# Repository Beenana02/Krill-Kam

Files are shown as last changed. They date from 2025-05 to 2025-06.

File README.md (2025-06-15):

# Krill Kam 

Check out the Krill Kamera! A raspi 4 custom camera that's fully handheld.   
*PSA it's fish themed (that's why it's a krillfish camera name)*

### What is the Krill-Kam

The krill kam uses a Raspi pi cam module and Raspi to basically create a custom digital camera. It's based of the old sony handycam. It comes with it's own screen and app to take and view photos or videos. It can also record audio from a mini USB mic. Lastly, it is all powered with a simple LiPo battery!

### Why camcorder?
I wanted the camera to be more handycam shaped because my personal handycam's microphone and speaker are broken. I wanted to originally fix this, but I decided I would challenge myself with creating my own camera! (Plus repairing the Handycam seemed pretty sketchy :cry:)

camcorder plus krill fish = krill kam  

## Photos

### Camera itself

Uses USB storage to save photo and video
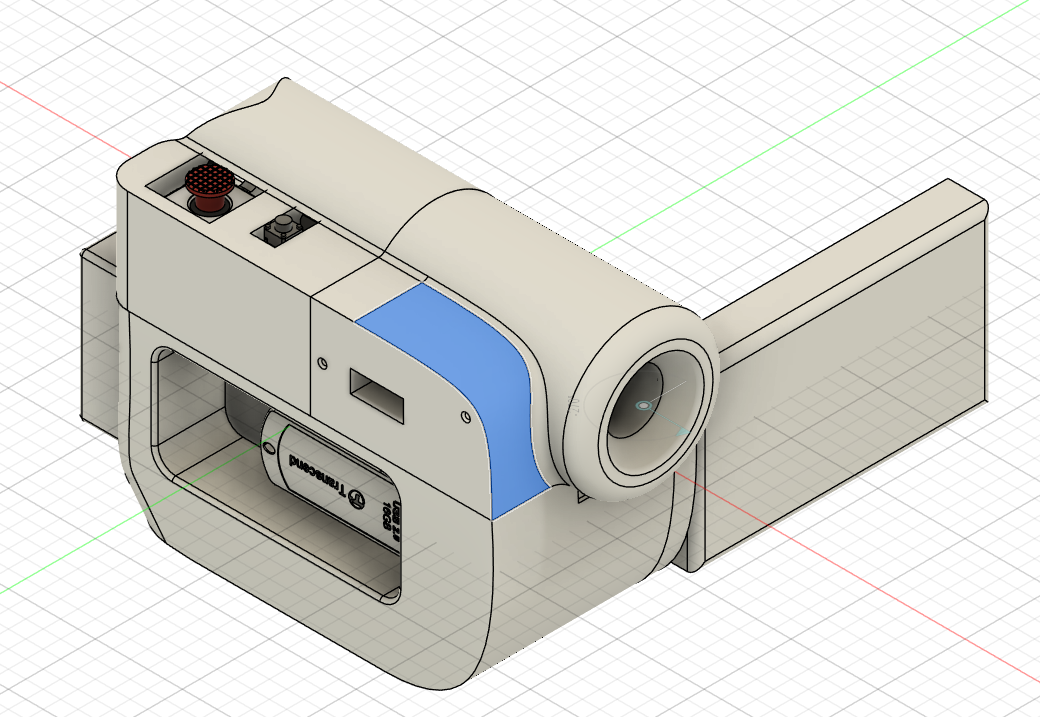
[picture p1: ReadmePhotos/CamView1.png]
view1
  

Has an inner panel for extra buttons and screens!
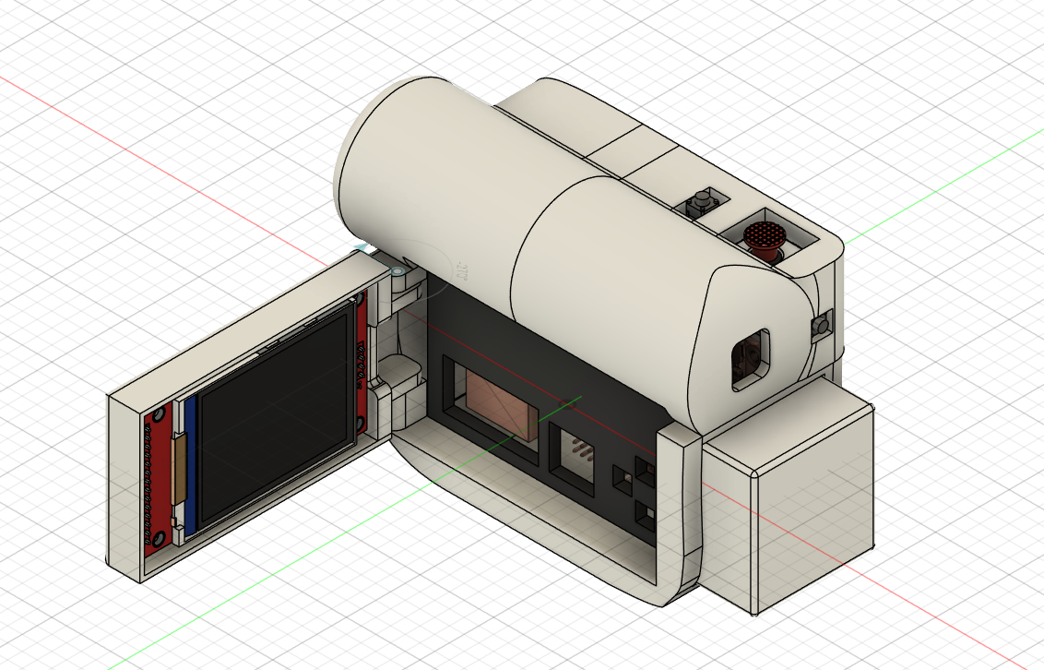
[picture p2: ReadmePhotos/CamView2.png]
view2
  

Arm with screen can open and close
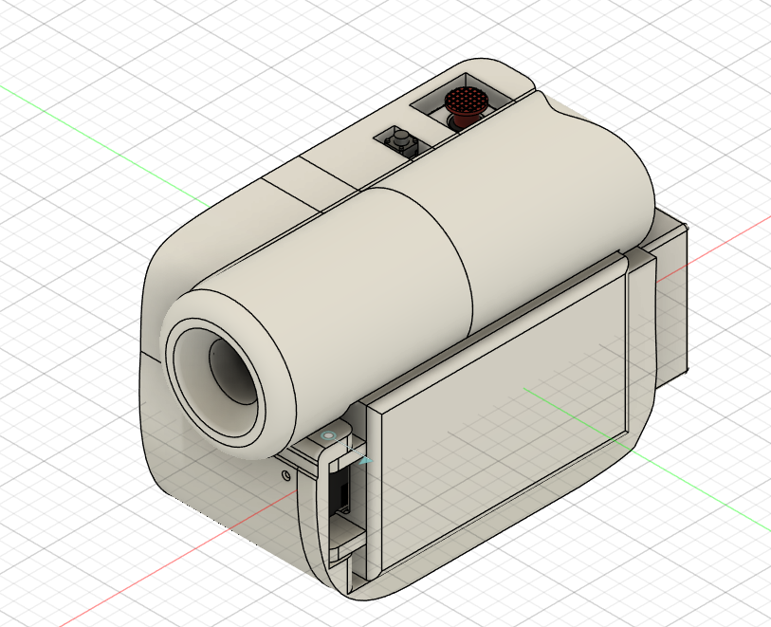
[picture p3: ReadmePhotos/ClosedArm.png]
Arm


> For more specific info read the journal!

## Wiring Diagram

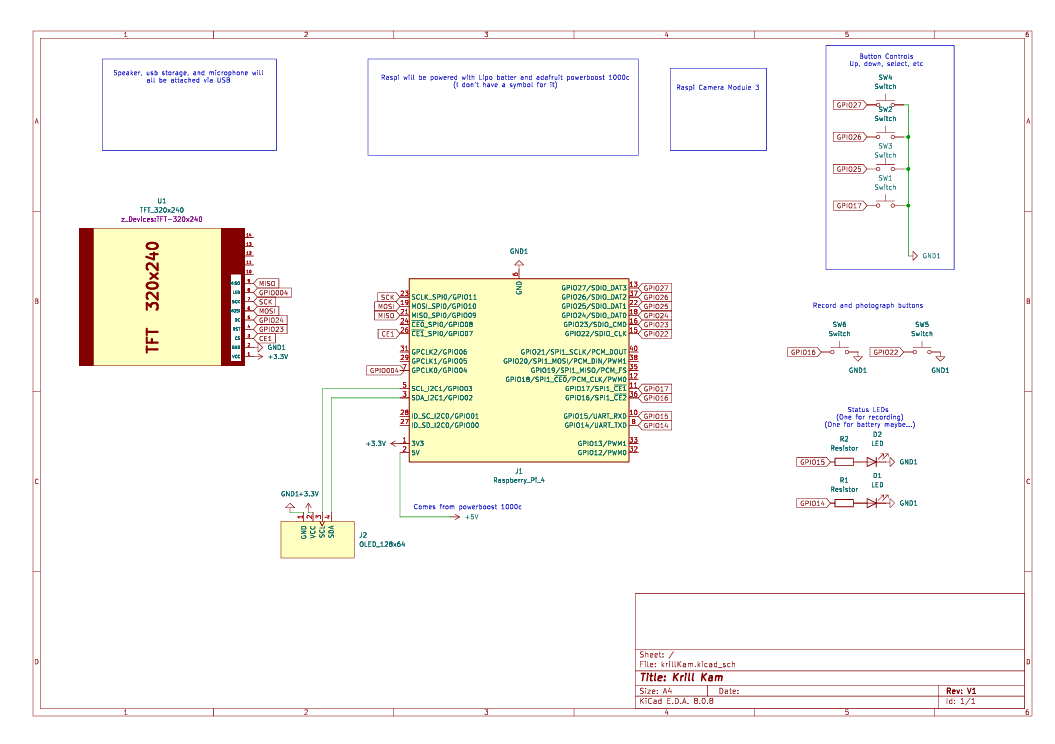
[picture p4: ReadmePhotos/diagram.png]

>look at the pdf for better view of diagram  

## BOM  

If it says own, that means I already have the item. Hopefully format is fine, I used a sheets to markdown generator so it may look a little off. Also total cost is **$126.07** this includes shipping, taxes, etc!

| Item Number | Description | Quantity | Link | Price  |
| --- | --- | --- | --- | --- |
| 1 | 2.4" TFT SPI Screen w/ Touchscreen | 1 | [Link](https://www.aliexpress.us/item/3256806129218488.html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) | 7.95 |
| 2 | PowerBoost 1000c | 1 | [Link](https://www.adafruit.com/product/2465) | 19.95  |
| 3 | Raspi 4 B | 1 | own | 0 |
| 4 | Raspi Cam module 3 | 1 | own | 0 |
| 5 | Mini 2-Axis Analog Thumbstick | 1 | [link](https://www.adafruit.com/product/2765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) | 2.5 |
| 6 | Analog Mini Thumbstick Breakout Board | 1 | [link](https://www.adafruit.com/product/3246) | 1.5 |
| 7 | Variety Pack Heatpress Inserts | 1 | [link](https://www.aliexpress.us/item/3256805603102147.html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) | 6.88 |
| 8 | USB 3.0 Right Angle Adapter | 1 | [link](https://www.aliexpress.us/item/3256805983682595.html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) | 1.49 |
| 9 | Hook Up wire 22awg | 1 | [link](https://www.digikey.com/en/products/detail/adafruit-industries-llc/1311/6198255) | 15.95  |
| 10 | LiPo 6000mAh battery 3.7v | 1 | [link](https://www.amazon.com/MakerHawk-6000mAh-Rechargeable-Protection-Insulated/dp/B0D7MBBS5N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) | 16.99  |
| 11 | eye screws for charms | 1 | [link](https://www.aliexpress.us/item/2255800041458653.html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) | 2.06 |
| 12 | Mini USB microphone | 1 | [link](https://www.adafruit.com/product/3367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) | 5.95 |
| 13 | Mini OLED screen (display battery health) | 1 | own | |
| 14 | Heatsink for Raspi | 1 | [link](https://www.adafruit.com/product/3084) | 0.95 |
| 15 | USB speaker | 1 | [link](https://www.adafruit.com/product/3369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) | 12.5 |
| 16 | Perfboard | 1 | [link](https://www.aliexpress.us/item/3256807162768193.html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) | 7.27 |
| 17 | Micro USB male to female cable | 1 | [link](https://www.amazon.com/Extension-Micro-B-Transferring-Suitable-Samsung/dp/B07MC7YSR2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) | 5.99 |
| 18 | Camera hand strap | 1 | [link](https://www.aliexpress.us/item/3256803849243891.html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) | 2.75 |
| 19 | Buttons | 6 | own | |
| | Cost without taxes/ shipping | | | 110.68 |
| | Cost final | | added $5 extra incase I got some of the taxes wrong | 126.07 |

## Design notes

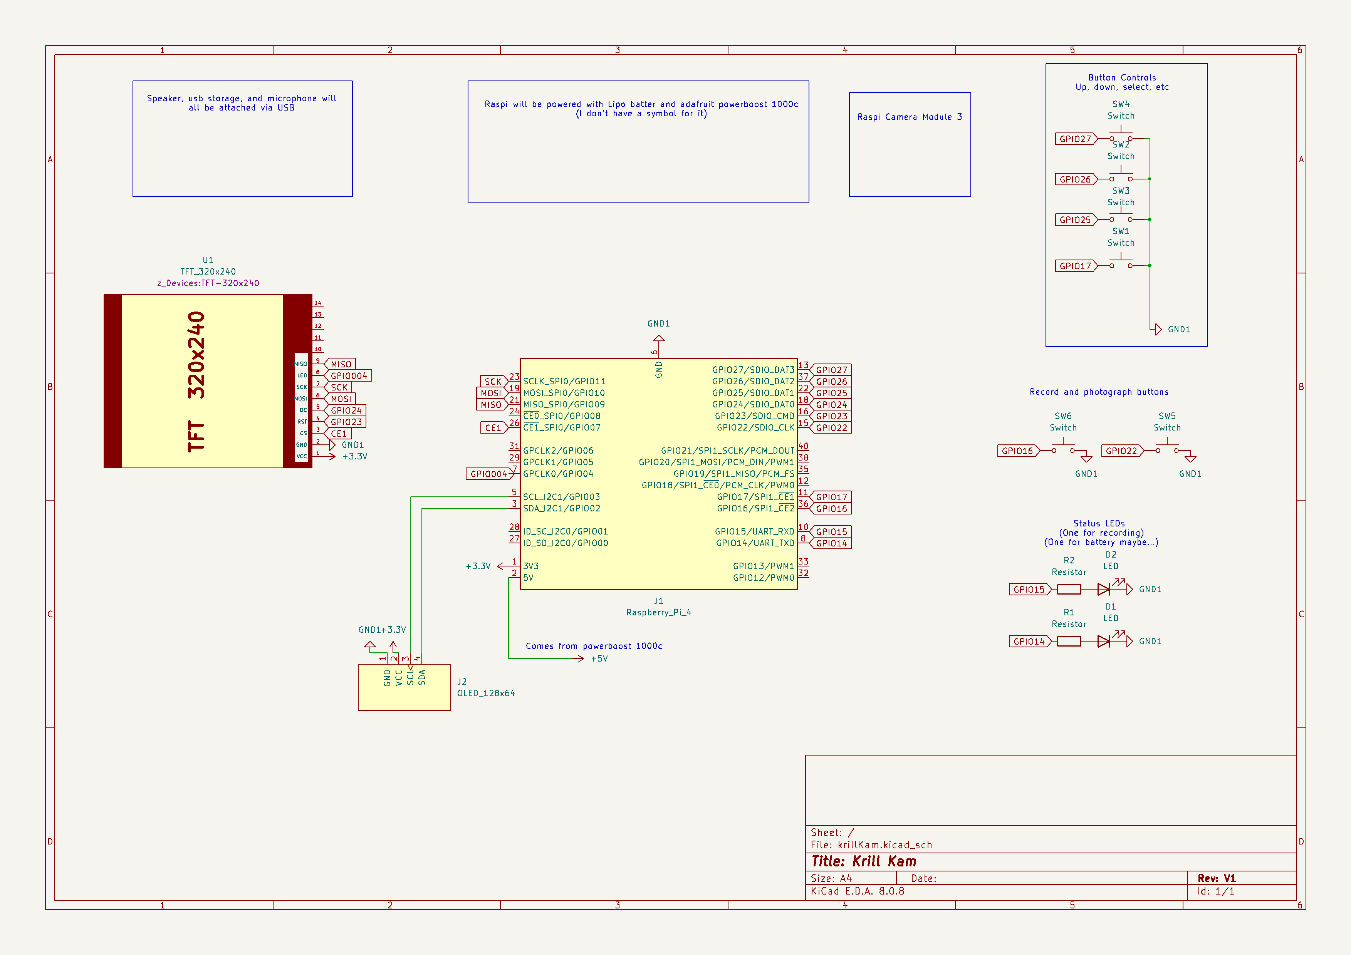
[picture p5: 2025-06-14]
image.png

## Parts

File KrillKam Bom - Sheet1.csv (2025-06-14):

Item Number | Description | Quantity | Link | Price
1 | 2.4" TFT SPI Screen w/ Touchscreen | 1 | Link | 7.95
2 | PowerBoost 1000c | 1 | Link | 19.95
3 | Raspi 4 B | 1 | own | 0
4 | Raspi Cam module 3 | 1 | own | 0
5 | Mini 2-Axis Analog Thumbstick | 1 | link | 2.5
6 | Analog Mini Thumbstick Breakout Board | 1 | link | 1.5
7 | Variety Pack Heatpress Inserts | 1 | link | 6.88
8 | USB 3.0 Right Angle Adapter | 1 | link | 1.49
9 | Hook Up wire 22awg | 1 | link | 15.95
10 | LiPo 6000mAh battery 3.7v | 1 | link | 16.99
11 | eye screws for charms | 1 | link | 2.06
12 | Mini USB microphone | 1 | link | 5.95
13 | Mini OLED screen (display battery health) | 1 | own
14 | Heatsink for Raspi | 1 | link | 0.95
15 | USB speaker | 1 | link | 12.5
16 | Perfboard | 1 | link | 7.27
17 | Micro USB male to female cable | 1 | link | 5.99
18 | Camera hand strap | 1 | link | 2.75
19 | Buttons | 6 | own
 | Cost without taxes/ shipping |  |  | 110.68
 | Cost final |  | added $5 extra incase I got some of the taxes wrong | 126.07

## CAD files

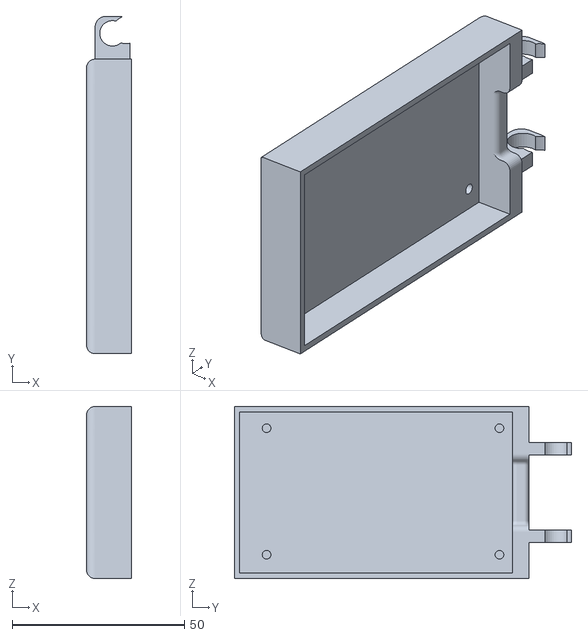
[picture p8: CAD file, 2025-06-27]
Case/V3/V3_Arm.stl
13.1 x 97.9 x 49.9

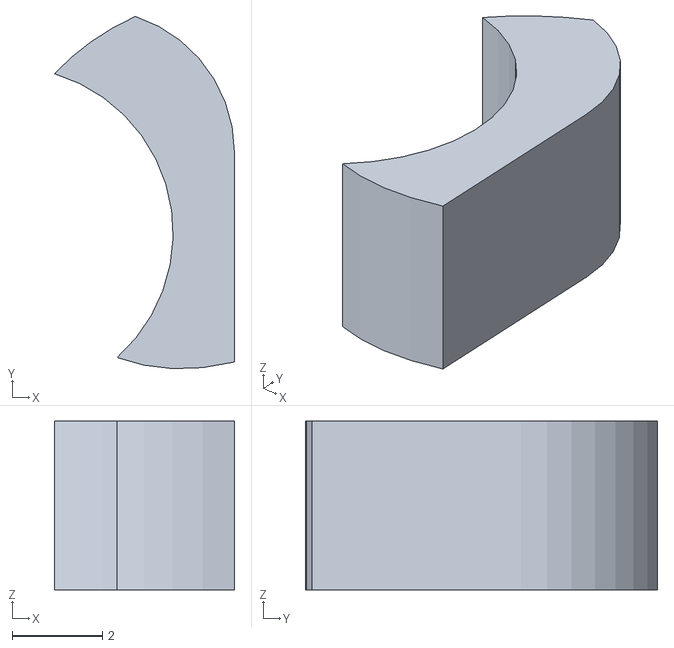
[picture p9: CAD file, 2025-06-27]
Case/V3/V3_ArmLock.stl
3.99 x 7.80 x 3.73

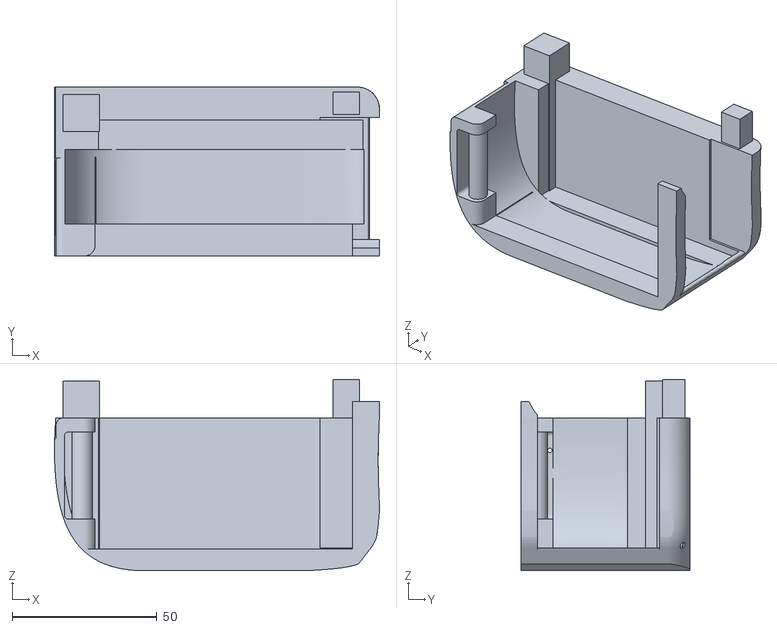
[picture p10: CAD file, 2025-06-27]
Case/V3/V3_Base.stl
112.4 x 58.4 x 66.2

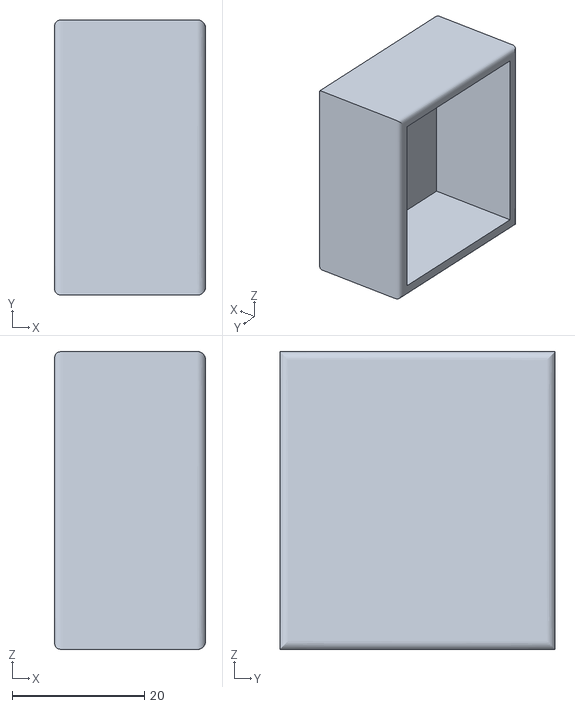
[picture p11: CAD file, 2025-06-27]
Case/V3/V3_FakeBatteryBack.stl
22.9 x 41.6 x 45.0

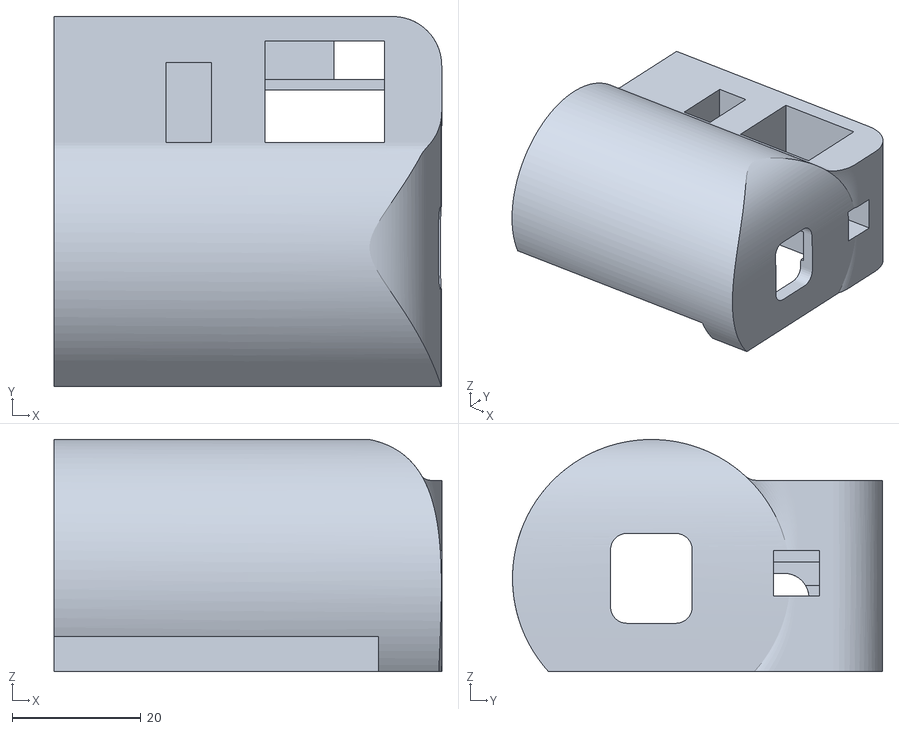
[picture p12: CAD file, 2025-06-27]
Case/V3/V3_Top1.stl
60.2 x 57.5 x 36.1

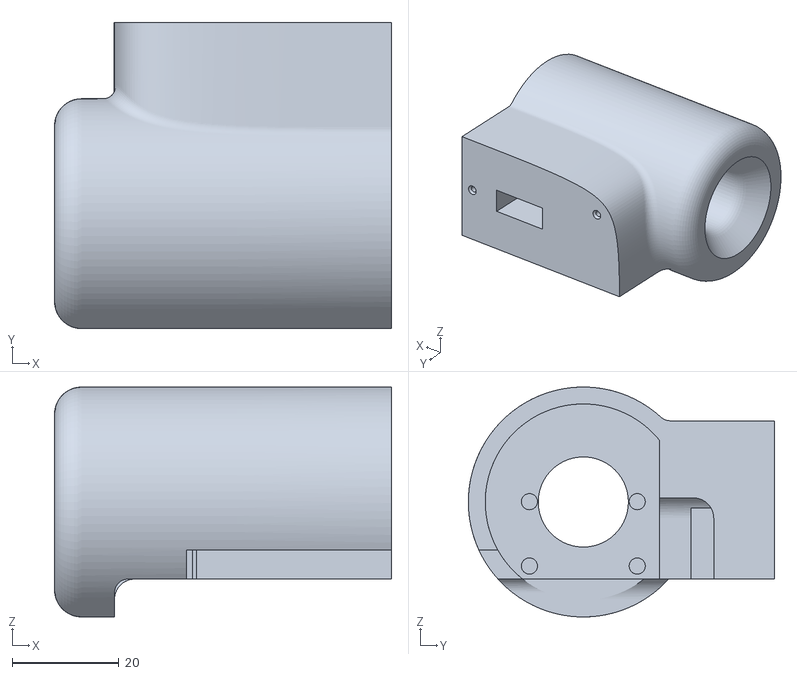
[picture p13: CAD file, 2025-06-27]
Case/V3/V3_Top2.stl
63.3 x 57.5 x 43.2

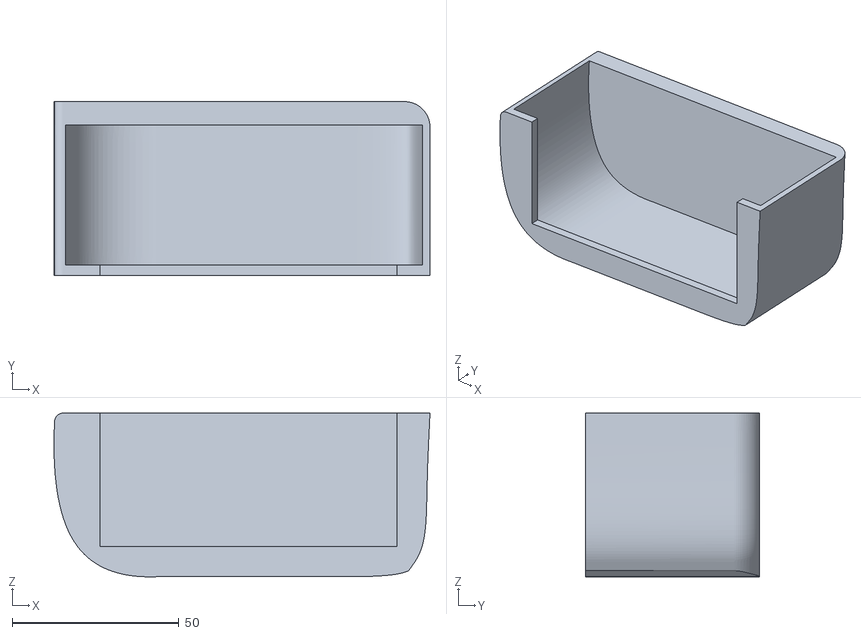
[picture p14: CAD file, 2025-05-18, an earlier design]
Case/V1/Base1.stl
112.7 x 52.1 x 49.1

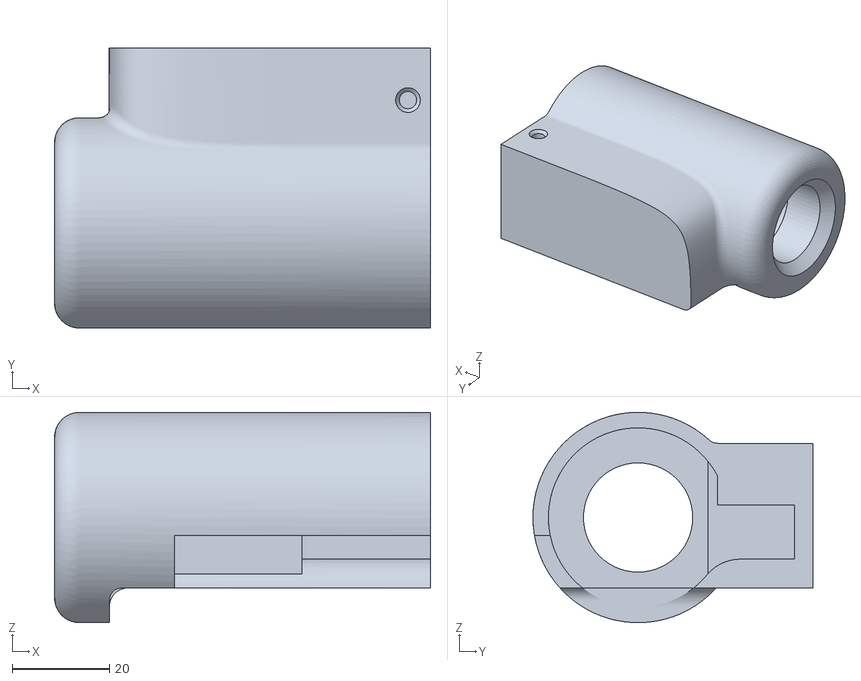
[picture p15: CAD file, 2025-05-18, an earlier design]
Case/V1/Top2.stl
77.2 x 57.5 x 43.2

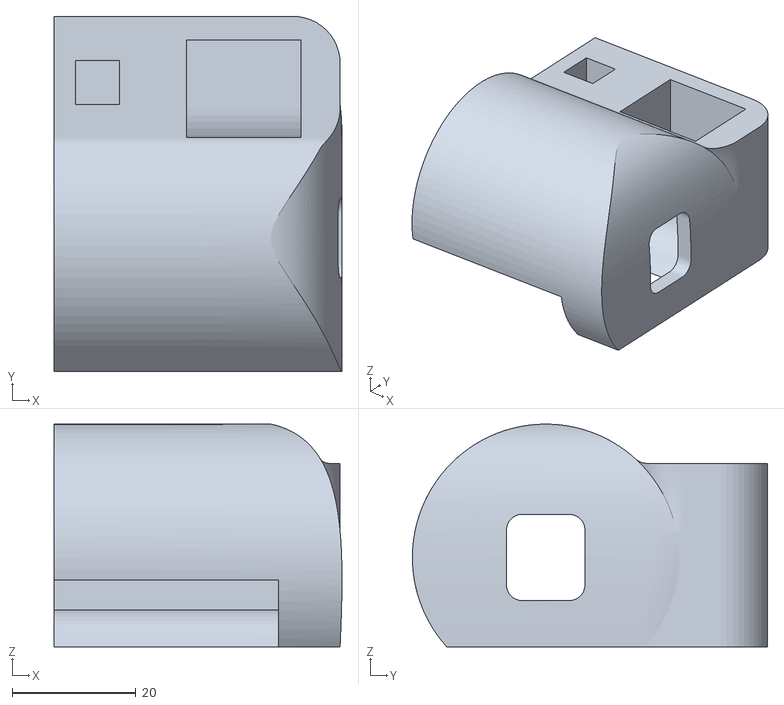
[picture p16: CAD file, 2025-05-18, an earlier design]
Case/V1/Top1.stl
46.6 x 57.5 x 36.1

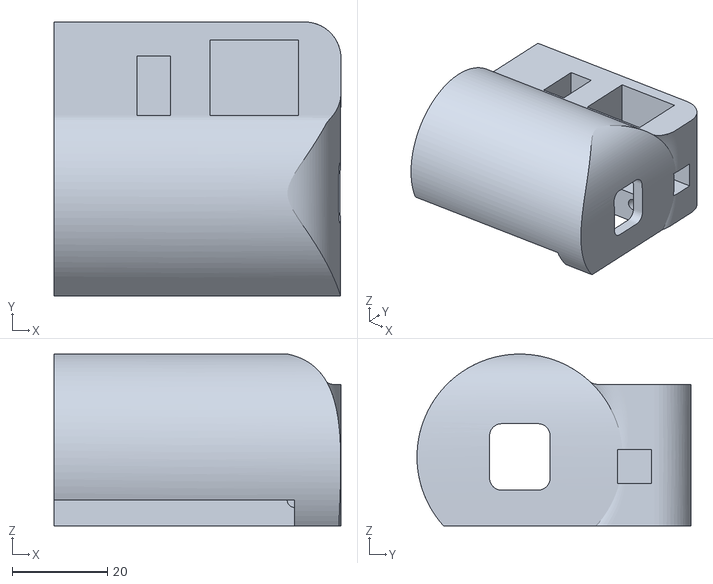
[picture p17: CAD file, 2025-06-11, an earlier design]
Case/V2/TopSplit2.stl
60.2 x 57.5 x 36.1

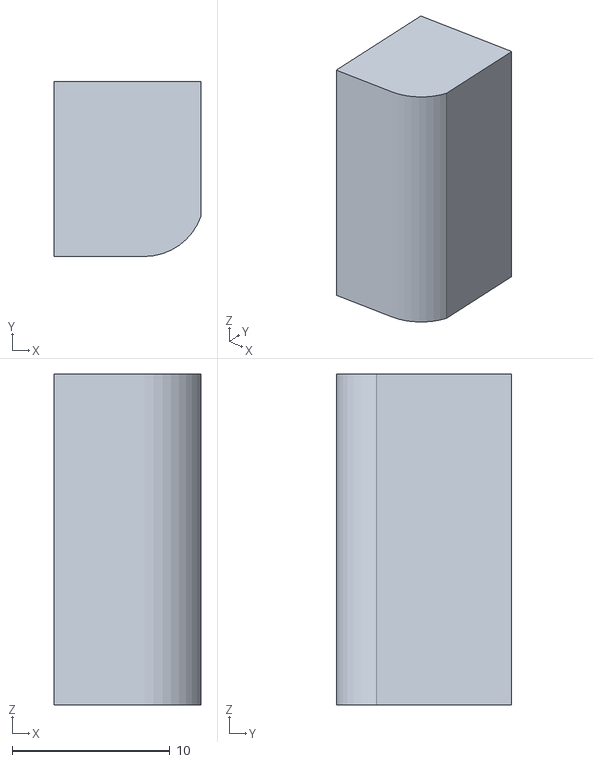
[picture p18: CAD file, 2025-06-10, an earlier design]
Case/V2/HingeHider.stl
9.32 x 11.1 x 21.0

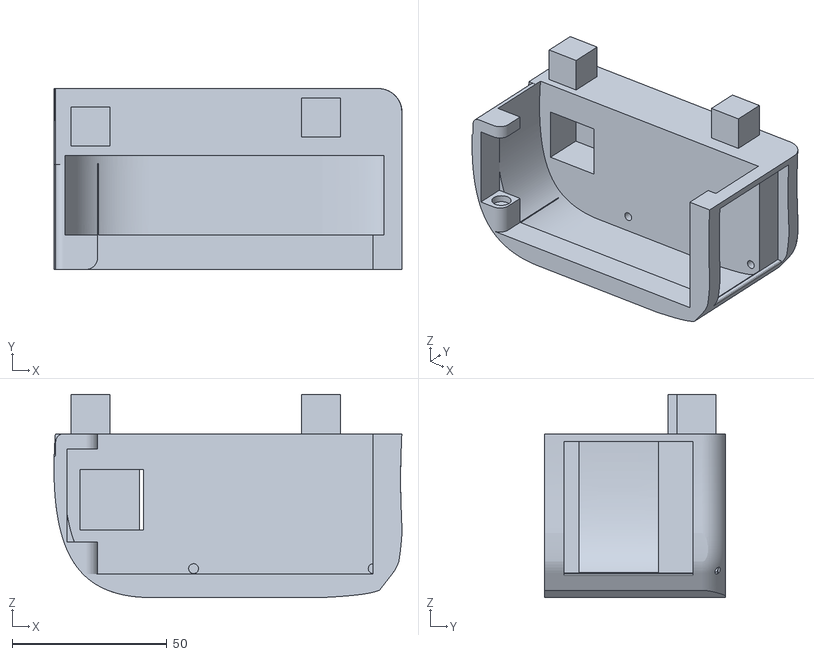
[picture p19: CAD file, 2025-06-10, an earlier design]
Case/V2/V2Base.stl
112.4 x 58.4 x 65.6

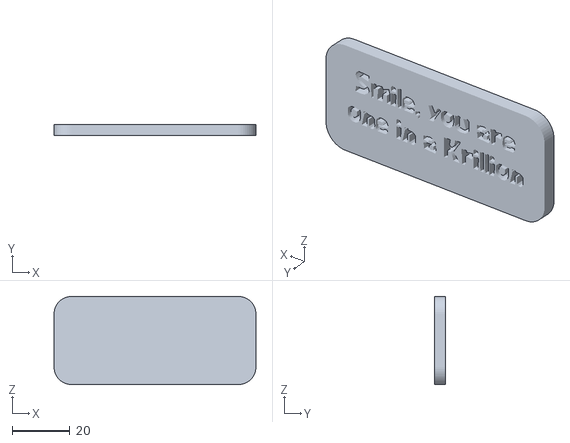
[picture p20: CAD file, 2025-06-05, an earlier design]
Case/V2/StoragePanel.stl
69.8 x 3.81 x 30.5

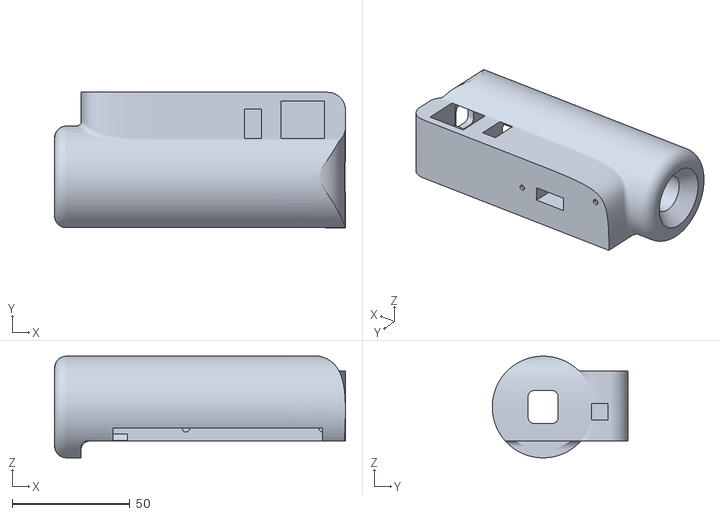
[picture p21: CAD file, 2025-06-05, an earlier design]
Case/V2/V2Top.stl
123.5 x 57.5 x 43.2

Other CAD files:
Case/V2/ScreenArm.stl
Case/V2/TopSplit1.stl
Case/V2/BatteryHolder.stl
Case/V2/InnerPanel.stl

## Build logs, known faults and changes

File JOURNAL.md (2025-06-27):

---
title: "Krill Kam"
author: "Gabi"
description: "Raspi-4 camera inspired by the Handycam"
created_at: "2025-05-16"
---

# Krill Kam Updates

Howdy wanna see the krill kam grow? 

Check out the updates below! :eyes::shrimp: [^1]
[^1]: I've spent 27.5 hours total on this project so far 😺

## May 16th: Sketching
Got in a rough idea of what I want the Camcorder to look like. It is based off the Sony Handy Cam that I have at home. 

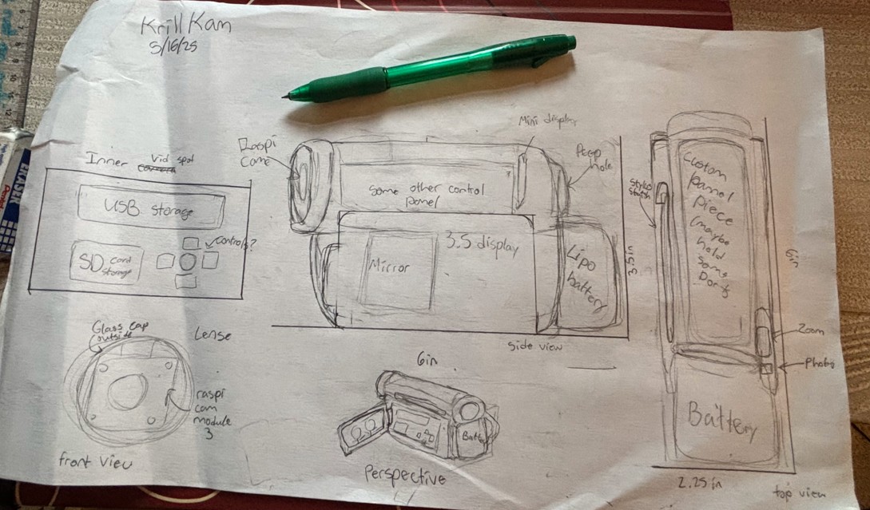
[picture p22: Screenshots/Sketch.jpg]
Planning Sketch


> Time Spent (Sketching) ~ 1 hour

## May 17th: First CAD & Print
Today I was just creating the Basic CAD model for the camera. I plan on making a full CAD when I figure out what parts I'll use. I already have a screen and raspi 4 at home so I have some basic dimensions for that.  

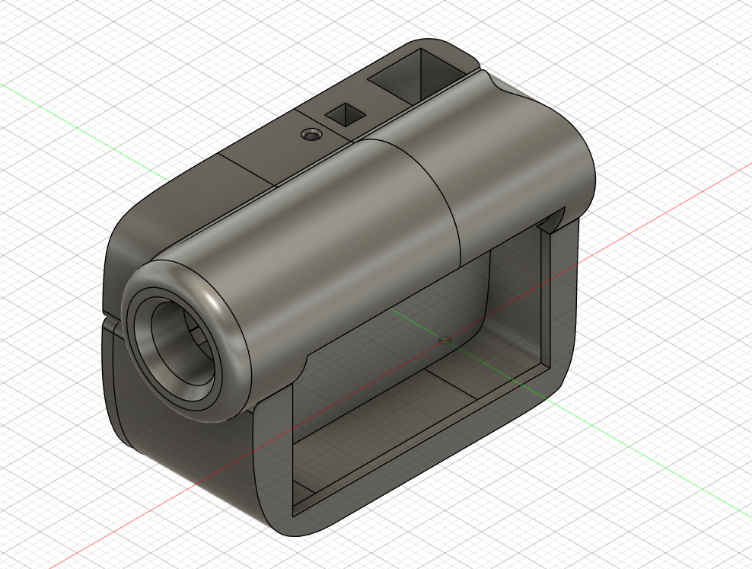
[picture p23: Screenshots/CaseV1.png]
First CAD


> Time Spent (CAD and printing) ~ 2.5 hours

## May 18th: Updating CAD

Didn't do too much today, just focused on updating the CAD model based on how the first CAD printed. Found some issues with clearance and fitting the Raspi in the actual shell. I revamp the inside to have a notch for the raspi and enough room for wires, buttons, proto boards, etc. Anyways, I still need to work on the actual pull out screen part and battery compartment.  

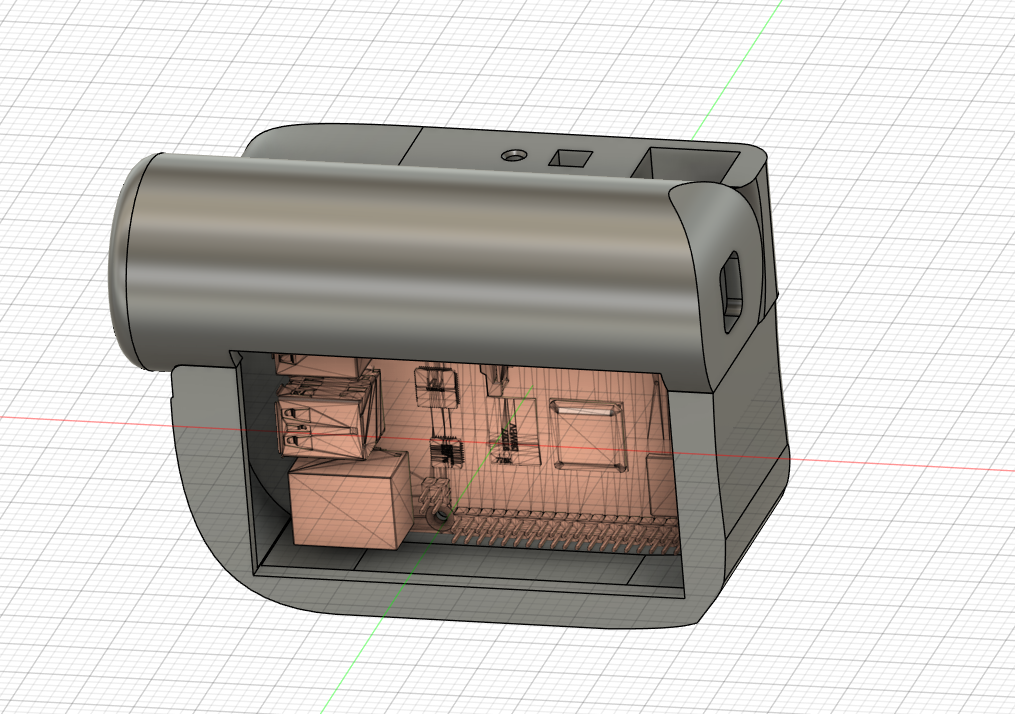
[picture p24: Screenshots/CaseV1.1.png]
Updated Case


> Time Spent (CAD) ~ 1 hour

## May 25th: Arm In CAD

Today I wanted to get the arm part with the hinge modeled in Fusion. This was my first time modeling a hinge and using the join feature in fusion. I went off a hinge design based on Maker's Muse's snap hinge in his video "Incredibly Handy 3D Printed Hinges!". I got the hinge to work with a bit of struggle at first, but overall I'm happy with the model. I plan on printing out the model one more time to figure out sizing, but the only thing left is to find where I'll put the power supply in the case.  

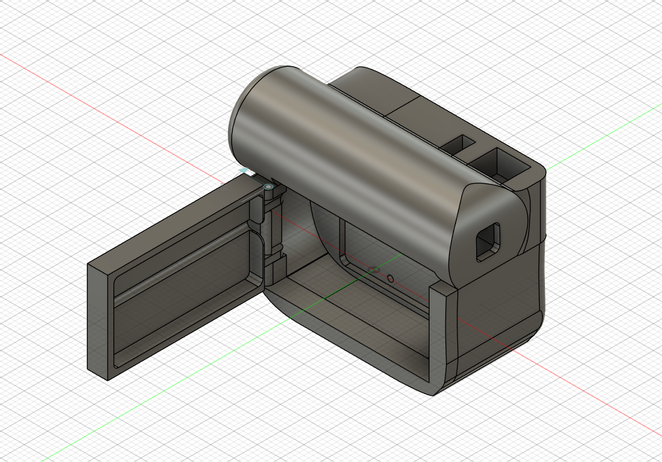
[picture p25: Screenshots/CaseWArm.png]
Cam with a arm to hold screen


> Time Spent (CAD) ~ 3 hours

## May 30th: Battery holder in CAD + some shopping

I modeled a little case on the end of my camera to hold the batteries and some remodeling on the holes for buttons. I'm still not sure what battery type i'll be using but I'm leaning towards a Li-Po with 5v converter and battery charger PCB like the Adafruit PowerBoost 1000. For the shopping, I think I've decided on using the Waveshare 2in touch display module for my main screen and the 0.85 LCD display module for the view hole screen. I plan on writing some test scripts just to get the camera working, but I won't be able to test the displays until I get them.  
 
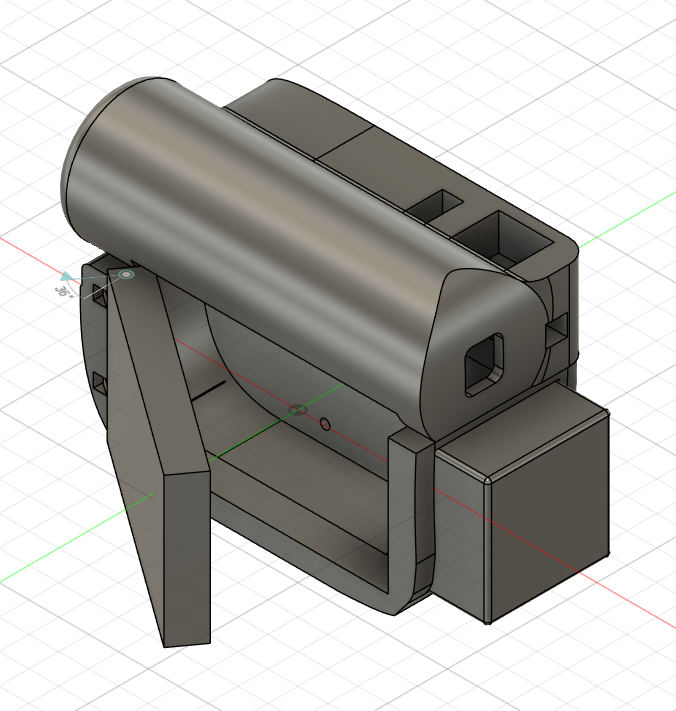
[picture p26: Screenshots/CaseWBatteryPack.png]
Cam with battery pack


> Time Spent (CAD) ~ 1.5 hours

## June 4th: Battery holder in CAD + some shopping

Today I coded some more on the camera app script by adding in new features to allow button presses to turn on and off the preview. I also worked a bit on the CAD and finally decided on the screen I will use for the camera. I'm going with a 2.4" TFT display since it fits perfectly inside my arm.  
 
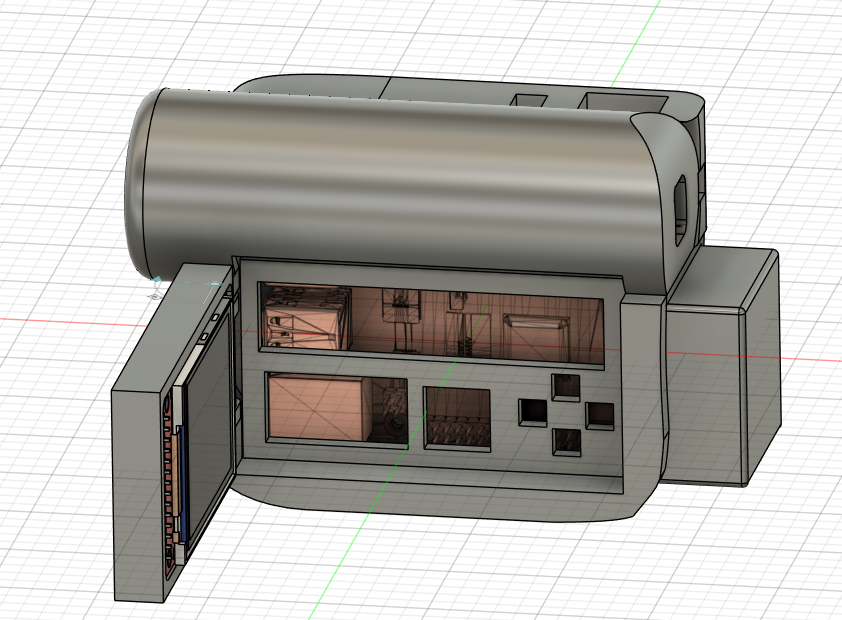
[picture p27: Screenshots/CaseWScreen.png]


> Time Spent (CAD+Code) ~ 1 hour

## June 5th: V2 of model DONE!

The case is done! I modeled in a spot to place the USB flashdrive in. I plan on using a flash drive to store the photos. I also place in components such as the buttons on the top of the case (not in picture). Lastly, I added in some text and remodeled the arm/ screen holder to have points to drill in the screen. The STL files are available in the [case folder](Case/V2).  

Also make sure to check out the [video](Screenshots/KrillKamCaseV2.mp4) in the screenshots folder for a short overview of the camera model.  

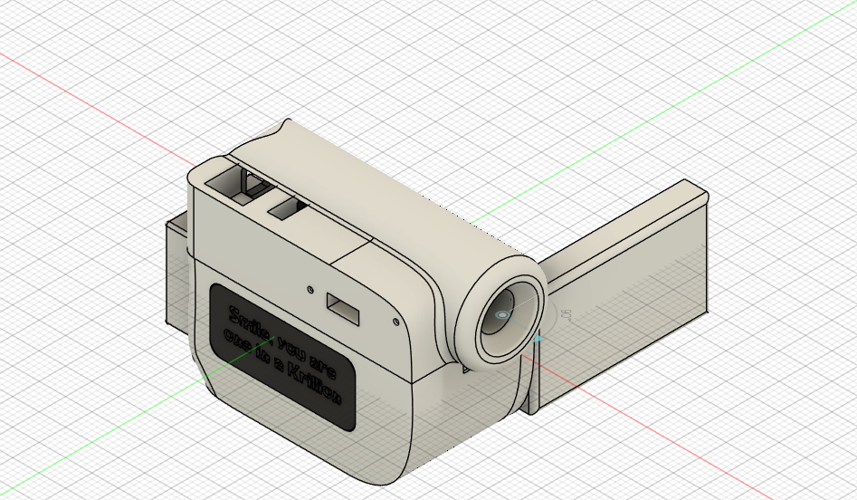
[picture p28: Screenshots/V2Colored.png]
Krill Kam Colored


> Time Spent (CAD) ~ 2.5 hours

## June 8th: Finished BOM

Today I began printing out the parts for krill kam case. I also finished the BOM of what items I need to buy. The total came to around $110 without shipping, but I'm sure with coupons and deals I will be able to get that price down. Also I settled on getting the battery off of Amazon even though it was pricey just because of shipping reasons. Anyways below is a photo of the pieces I have printed out so fall (arm, battery shell, and USB panel cover) more is printing now!   

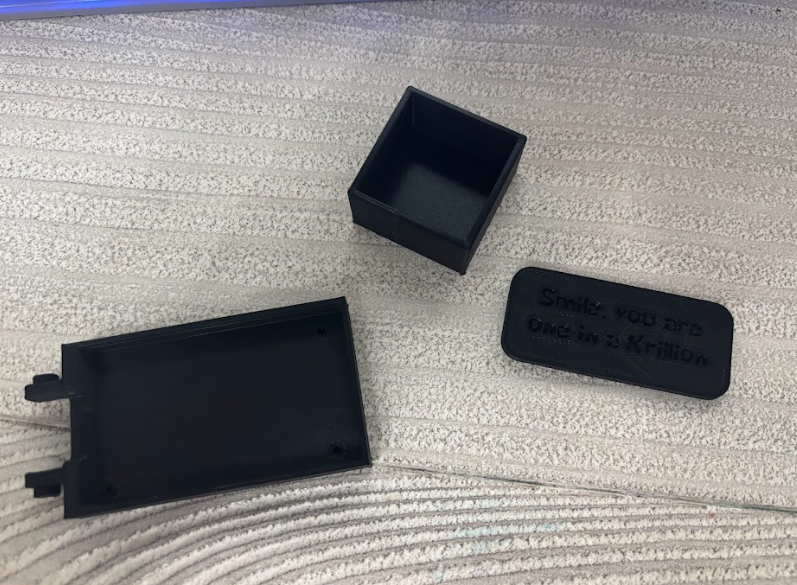
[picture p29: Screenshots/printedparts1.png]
arm, battery shell, and USB panel cover


> Time Spent (CAD) ~ 0.5 hours

## June 9th: Updated Hinge design

Today I printed out the base and notice 3 problems with clearances.  

1. I couldn't get the battery shell to fit in smoothly, so I added in some extra clearance to the hole on the back of the base.
2. The USB panel cover didn't fit in, so I added more clearances.
3. Lastly, the arm couldn't be attached to the base, so I got rid of the notch in the center and will print that part on its own and glue it back in.    

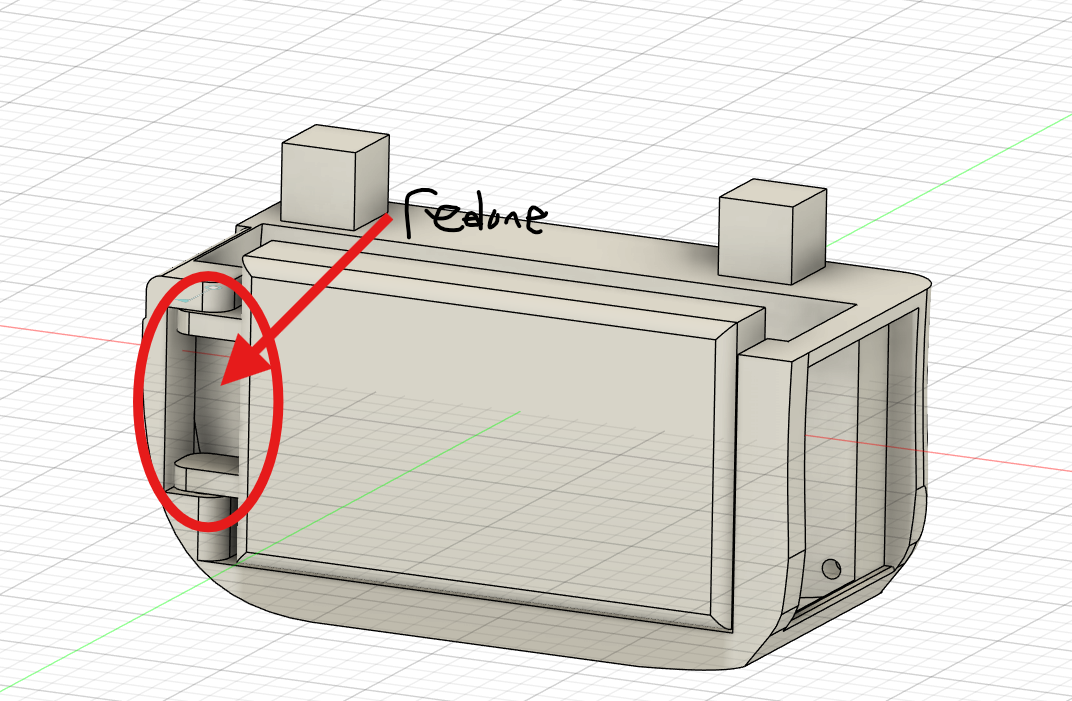
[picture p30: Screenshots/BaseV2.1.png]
fixed hinge


> Time Spent (CAD) ~ 0.5 hours

## June 11th: Printed case!

I fixed the problems with the base and reprinted the parts. I now have a full shell of the krill kam! I also did a bit of work on the gui code, but still working on layout stuff.  

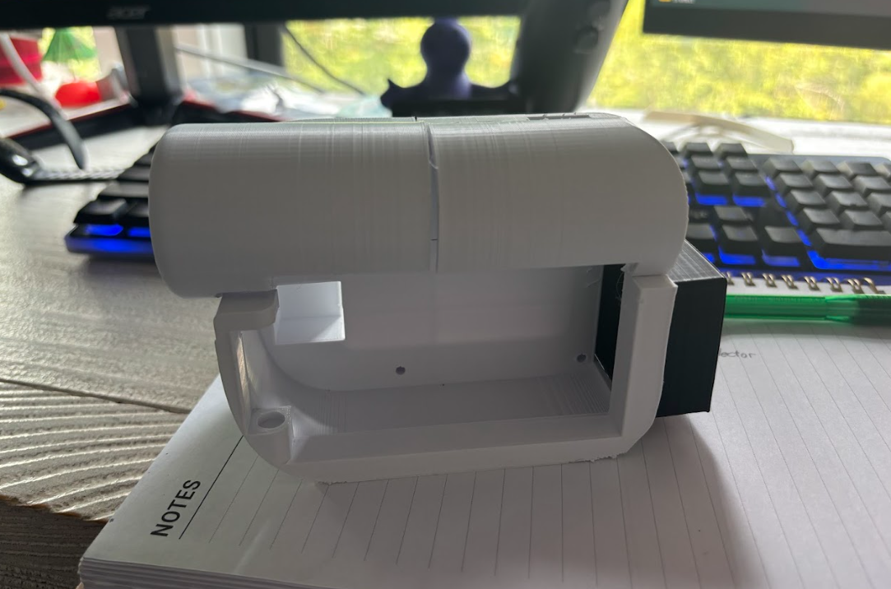
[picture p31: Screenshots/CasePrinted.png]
Case


> Time Spent ~ 1 hour

## June 12th: GUI with live camera feed

Today I got a background on my camera app, along with a live feed of the camera using OpenCV. I watched some of clear code's "The ultimate introduction to modern GUIs in Python [ with tkinter ]" to get the background image working and general knowledge on Tkinter. I also used Jake's Science Shop's "Adding a Webcam Stream to our Python - Tkinter Drone Controller | Part 2: GUI Video Stream" video to get OpenCV working with my app. Now I just need to fix the scaling issues with the camera and add in the rest of app features. I want a photo viewing mode, camera controls like zoom and focus, accurate time/date, and fun fish themed features! For now I've been using frutiger aero photos as my background, but I plan to shift into creating my own icons and backgrounds using pixel art!   

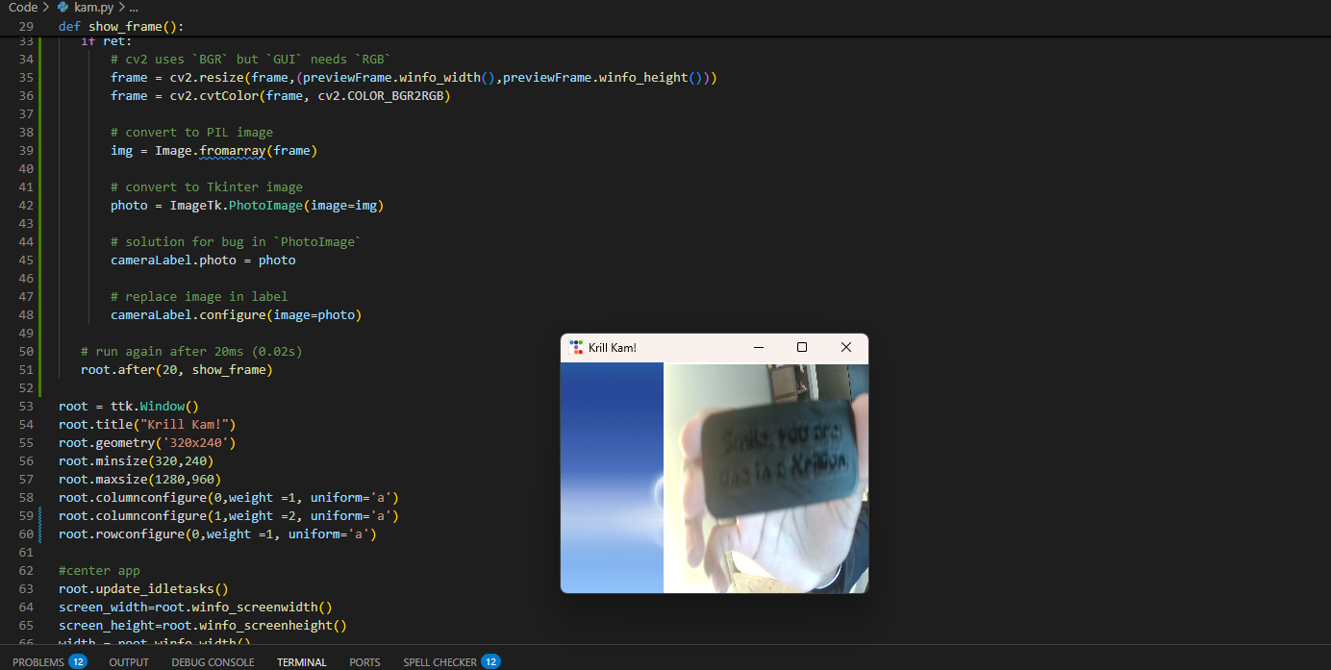
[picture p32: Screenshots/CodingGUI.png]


> Time Spent ~ 3 hours

## June 13th: Fixed camera feed and read me

I spent all of today trying to fix the camera feed so that the camera aspect ratio stays the same no matter the screen size. I got it to work using some ratio of camera height to width and comparing it with the window height and width. The code I learned yesterday when creating a background that resizes with app was what I based off today's code. I also added place holder buttons as well. Lastly I got my readme polished and I think I'm ready to submit for my grant. Hopefully I can get the screen part soon(it will help me a lot with creating the GUI).  

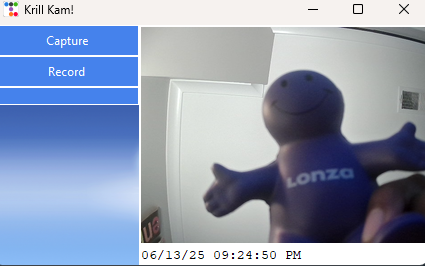
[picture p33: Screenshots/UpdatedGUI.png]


> Time Spent ~ 3 hours

## June 15th: new windows on GUI

Today I used the top level widget to create 2 new windows for the app. I now have a window for powering off the camera and a window to review photos. The window can't quite cycle through photos yet, but I am working on that at the moment. I think i'll try the same idea as I saw in geeks for geeks tutorial on creating a image viewer app with tkinter.    

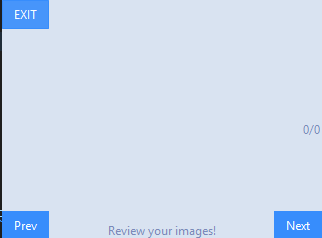
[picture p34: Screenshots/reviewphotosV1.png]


> Time Spent ~ 2 hours

## June 16th: Photo review works

I got the photos to cycle through using PIL to load the images and a custom function to make the photos fit to screen. Lastly, I got the photo buttons to work and allow the user to go forwards and backwards through the photos. I also used the OS library to make sure that only photo images would load in the photo review window. 

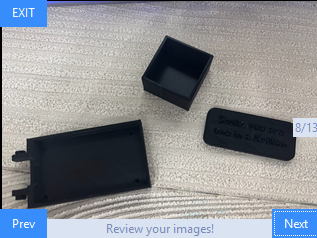
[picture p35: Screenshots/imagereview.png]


> Time Spent ~ 1 hour

## June 18th: Power Down window done

I finished up the power down menu today. I made a simple background using a photo I found from NASA. I then added some text in canva and saved the photo as a png. Lastly, I updated the code to display the image and I think it looks pretty good   

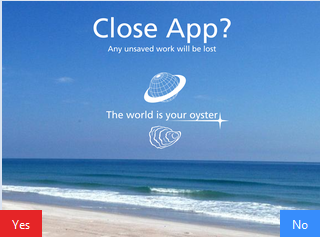
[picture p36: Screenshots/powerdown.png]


> Time Spent ~ .5 hours

## June 23th: Re-CAD

I was gone a bit for a vacation, but today I got the battery for the camera in the mail. It was way bigger than I had modeled for and I might have accidentally read the measurements on the product wrong. So today was re-working the cad to allow the battery to fit in the camera base. To get the battery to fit, I had to remove the usb storage compartment to make space for the battery. As of now I'm not sure what to remodel in order to get the usb flashdrive to fit. My plan is to just have it where the inner panel will be or in the old battery holder section 

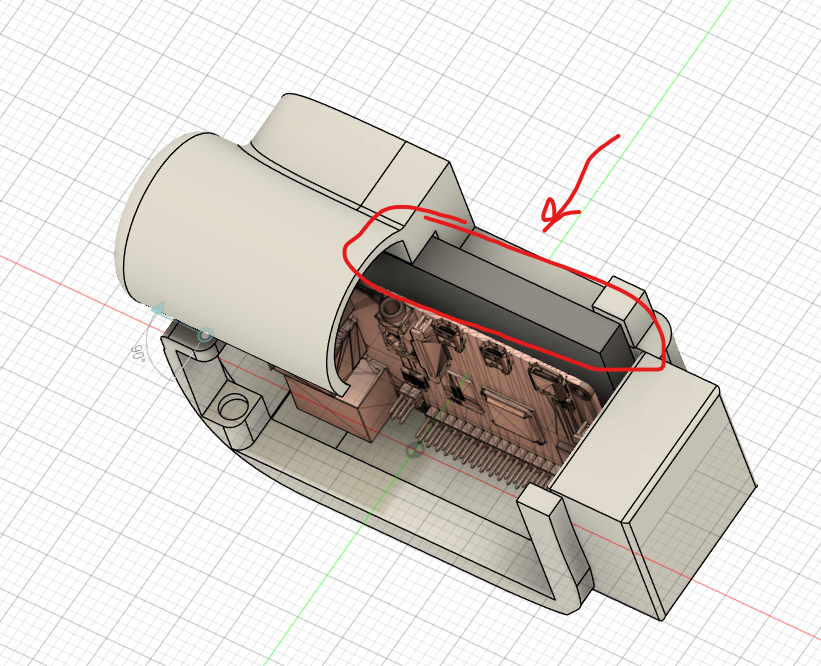
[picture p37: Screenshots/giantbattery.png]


> Time Spent ~ 2 hours

## June 26th: Re-CAD Arm and Joystick Slot

Finally got some time this week to work more on the project. I just got in all my adafruit items and I noticed that the PCB for the joystick was a bit bigger than I expected. To fix that I updated my CAD to allow for the PCB to sit above the battery. Also for today I worked on redoing the arm mechanic. I thought the hinge I had now was always getting loose on my V2 print, so I remodeled the hinge to be a clip on design. Now the base has a rod where the arm will clip onto and then you can glue another piece onto the arm to make sure the arm stays in place. All updates are in the V3 folder and I'm currently 3D printing them now!

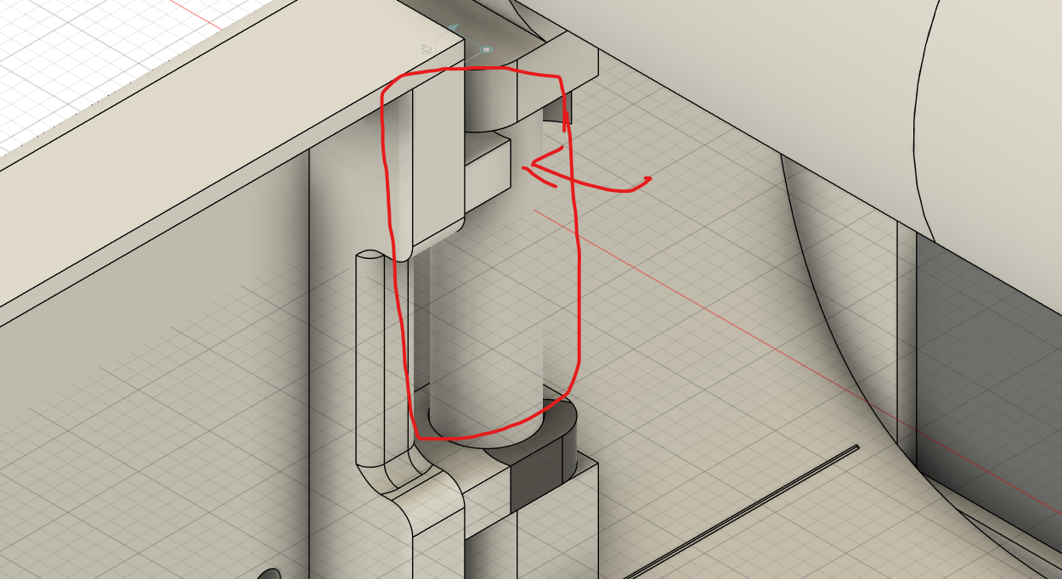
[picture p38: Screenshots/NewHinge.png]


> Time Spent ~ 1.5 hours

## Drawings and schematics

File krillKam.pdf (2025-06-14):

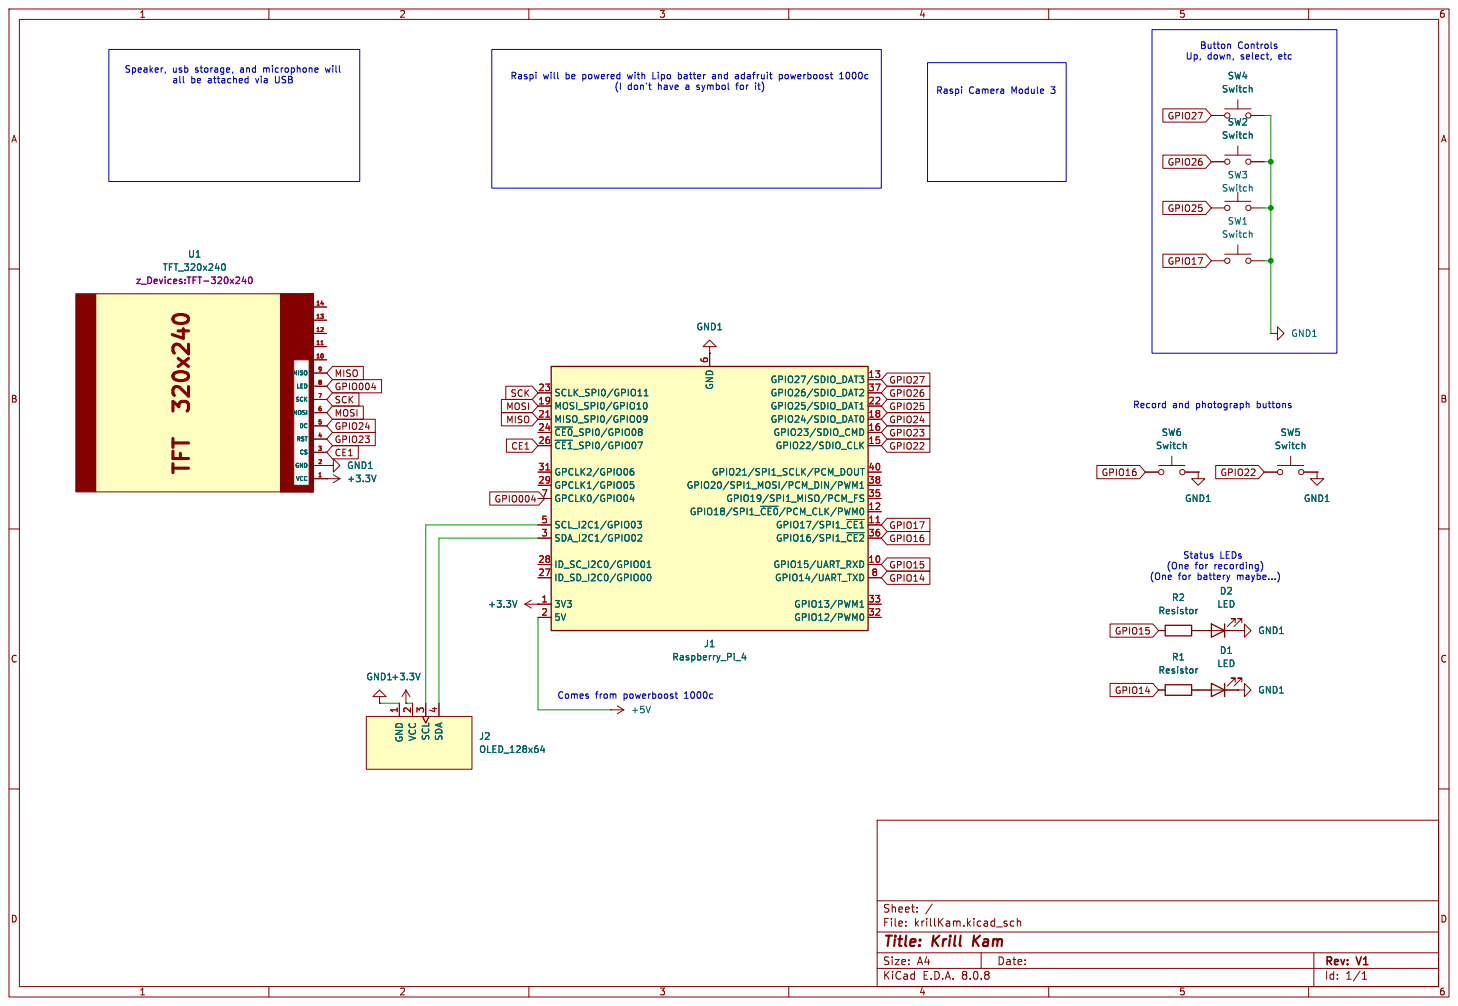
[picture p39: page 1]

(I don't have a symbol for it)

(One for recording)
(One for battery maybe...)

Id: 1/1 Title: Krill Kam

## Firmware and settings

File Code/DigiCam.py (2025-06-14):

from time import strftime
import pygame
from gpiozero import Button
from picamera2 import Picamera2, Preview
from picamera2.encoders import H264Encoder

cam = Picamera2()
previewB = Button(14)
photoB = Button(15)
videoB = Button(18)

#set preview parameters
#previewPara = cam.create_preview_configuration(Preview.QT)
video_config = cam.create_video_configuration()
cam.configure(video_config)
encoder = H264Encoder()


turnedOn = True
recording = False

cam.start_preview(Preview.QTGL)
cam.start(show_preview=True)


def capture():
    currentTime= strftime("%d-%m-%y-%I:%M:%S")
    #make sure to change this to your wanted save location
    cam.capture_file('/home/krill/camera/'+currentTime+'.jpg')
def video_capture():
    if(recording == True):
        currentTime= strftime("%d-%m-%y-%I:%M:%S")
        cam.start_recording(encoder, '/home/krill/camera/'+currentTime+'.h264')
    elif(recording == False):
        cam.stop_recording()

while True:
    if previewB.is_pressed:
        if(turnedOn == True):
            turnedOn = False
            cam.stop_preview()
        elif(turnedOn == False):
            turnedOn = True
            cam.start_preview(Preview.QTGL)
    if videoB.is_pressed:
        video_capture()
        if(recording == True):
            recording = False
        elif(recording == False):
            recording = True
    if(turnedOn == True and recording == False):
        photoB.when_pressed = capture

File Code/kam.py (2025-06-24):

import tkinter as tk
from tkinter import ttk
from tkinter import messagebox
import ttkbootstrap as ttk
import cv2
from PIL import Image, ImageTk
from time import strftime
import os

root = ttk.Window(themename='morph')
root.title("Krill Kam!")
root.geometry('320x240')
root.minsize(320,240)
root.maxsize(1280,960)
root.columnconfigure(0,weight =1, uniform='a')
root.columnconfigure(1,weight =5, uniform='a')
root.rowconfigure((0),weight =1, uniform='a')
root.rowconfigure((1),weight =2, uniform='a')
root.rowconfigure((2),weight =1, uniform='a')

# --- functions --- #
#fills images
def fill_image(event,imaged,ratio):
    global newImage_tk
    backgroundsRatio = event.width/event.height

    if backgroundsRatio>ratio:
        width =int(event.width)
        height =int(width/ratio)
    else:
        height =int(event.height)
        width =int(height*ratio)

    resizedImage= imaged.resize((width,height))
    newImage_tk=ImageTk.PhotoImage(resizedImage)
    backgrounds.create_image(int(event.width/2),
                             int(event.height/2), 
                             anchor ='center',
                             image=newImage_tk)

#fits to camera preview to canvas while keeping aspect ratio
def fit_image(image, width, height):

    old_width, old_height = image.size
    aspectRatio = old_width/old_height
    currentRatio=width/height
    if(currentRatio>aspectRatio):
        nHeight= height
        nWidth= int(nHeight*aspectRatio)
    else:
        nWidth=width
        nHeight=int(nWidth/aspectRatio)
    resizedImage= image.resize((nWidth,nHeight),Image.LANCZOS)
    return ImageTk.PhotoImage(resizedImage)

#camera stuff
def show_frame():
   # get frame
   ret, frame = cap.read()
   
   if ret:
       # cv2 uses `BGR` but `GUI` needs `RGB`
       
       cv2frame = cv2.cvtColor(frame, cv2.COLOR_BGR2RGB)

       # convert to PIL image
       img = Image.fromarray(cv2frame)

       #resize window

       widthS=int(previewArea.winfo_width())
       heightS=int(previewArea.winfo_height())
       resizedImage = fit_image(img,widthS,heightS)

       # convert to Tkinter image
       photo = resizedImage
       
       # solution for bug in `PhotoImage`
       cameraLabel.photo = photo
       
       # replace image in label
       cameraLabel.configure(image=photo)  
   
   # run again after 20ms (0.02s)
   root.after(20, show_frame)

#Gets fps of camera
def fps_counter():
    fps = cap.get(cv2.CAP_PROP_FPS)
    fpsLabel.config(text='FPS: '+str(fps))
    fpsLabel.after(2000, fps_counter)

#Gets local time
def time_now():
    currentTime= strftime('%D %I:%M:%S %p ')
    localTime.config(text=currentTime)
    localTime.after(1500, time_now)

#Power down camera
def power_off():
    powerWindow = tk.Toplevel()

    powerWindow.title("power off")
    powerWindow.geometry('320x240')
    powerWindow.grid_columnconfigure((0,1),weight=1,uniform='a')
    powerWindow.rowconfigure((0,1),weight=1,uniform='a')
    centerWindows(powerWindow)

    #display screen background
    load=Image.open('GUIimages/exitScreen.png')
    photo1=fit_image(load, 320, 240)
    background = ttk.Label(powerWindow,image=photo1)
    background.image = photo1
    background.grid(column=0,row=0, rowspan=2, columnspan=2, sticky='news')
    
    yesB=ttk.Button(powerWindow,text='Yes',command=lambda: root.destroy(), bootstyle='danger')
    yesB.grid(column=0,row=1, sticky='sw')
    noB=ttk.Button(powerWindow,text='No', command=lambda: powerWindow.destroy())
    noB.grid(column=1,row=1, sticky='se')


    #if powered off from screen it will display a popup message first then shutdown
            

    #if powered down from switch button it will complete a safe shutdown

#Review photos window
def create_photo_window():
    global photoLabel
    global prevK
    global nextK
    global counter
    global photo_window
    #basic canvas
    photo_window = tk.Toplevel()
    photo_window.title("Photo Reviewer")
    photo_window.geometry('320x240')
    photo_window.grid_columnconfigure((0,1),weight=1,uniform='a')
    photo_window.rowconfigure((0,1),weight=1,uniform='a')
    centerWindows(photo_window)

    #photo canvas
    photoLabel= ttk.Label(photo_window, text='place holder', background='black', anchor= 'center')
    photoLabel.grid(column=0,row=0,columnspan=photo_window.grid_size()[0], rowspan=photo_window.grid_size()[1])
    
    title = ttk.Label(photo_window,text='Review your images!',anchor='center')
    title.grid(column=0,row=1, columnspan=photo_window.grid_size()[0], sticky='sew')
    #forward/ backward options
    prevK = ttk.Button(photo_window,text='Prev', command= last_photo)
    prevK.grid(column=0,row=1,sticky='sw')
    nextK = ttk.Button(photo_window,text='Next', command= next_photo)
    nextK.grid(column=1,row=1,sticky='se')
    #photo counter + exit button
    counter = ttk.Label(photo_window, text=str(imageCounter)+'/'+str(len(photosPath)), anchor='center')
    counter.grid(column=1,row=1,sticky='ne')
    returnB = ttk.Button(photo_window,text='EXIT', command= lambda: photo_window.destroy())
    returnB.grid(column=0,row=0,sticky='wn')

    display_image(imageCounter)
    
def display_image(photoNum):
    global photo_window
    global counter
    if(photoNum< len(photosPath)):
        loaded = Image.open(photosPath[photoNum])
        widthS=int(photo_window.winfo_width())
        heightS=int(photo_window.winfo_height())-int(counter.winfo_height())
        newLoadedPhoto= fit_image(loaded, widthS, widthS)
        photoLabel.config(text= None, image=newLoadedPhoto)
        photoLabel.image = newLoadedPhoto

def next_photo():
    global imageCounter
    global counter
    if(0<= imageCounter < len(photosPath)):
        imageCounter += 1
        display_image(imageCounter)
        counter.config(text=str(imageCounter)+'/'+str(len(photosPath)))
    else:
        print('no more photos')
    print(imageCounter)
    
def last_photo():
    global imageCounter
    global counter
    if(0< imageCounter <= len(photosPath)):
        imageCounter -= 1
        display_image(imageCounter)
        counter.config(text=str(imageCounter)+'/'+str(len(photosPath)))
    else:
        print('no more photos')
    print(imageCounter)

#detects which photo the app is viewing
imageCounter = 0

# get photos from certain folder change this to the folder you want
imageFolder="C:/Users/Gabi/Documents/KrillKam/Krill-Kam-/Screenshots"
photosPath = []
def get_photos(folder):
    for photo in os.listdir(folder):
        photo_end= os.path.splitext(photo)[1]
        if(photo_end.lower() in {'.png','.jpeg','.jpg'}):
            photoPath = os.path.join(folder, photo)
            photosPath.append(photoPath)
get_photos(imageFolder)
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

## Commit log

2025-05-18 Added in first CAD of case
    [Base1.stl, Top1.stl, Top2.stl]
2025-05-24 CAD work from a few days ago
2025-06-03 Added in some on off camera display features
    Camera can now be turned on and off, still need to work on a capture button and overall gui for screen
2025-06-04 Added in buttons to start and stop preview
2025-06-05 Worked some more on the Case and tested out Tkinter for the first time!
2025-06-05 Finishing Up Case
    [BatteryHolder.stl, InnerPanel.stl, ScreenArm.stl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]
2025-06-09 New Bom
    [KrillKam Bom - Sheet1.csv]
2025-06-10 Today's fixes 6/9/25
    [HingeHider.stl, V2Base.stl]
2025-06-11 Code and CAD
    Split the top case for easier printing.
    Worked a bit on the video recording in digicam code.
    Lastly, playing around with tkinter and trying to create a usable app
    [ScreenArm.stl, TopSplit1.stl, TopSplit2.stl]
2025-06-13 creating final app for camera
2025-06-13 added in buttons and reworked camera sizing
    [kam.py]
2025-06-13 fixed problems with camera resizing as window changes, up next is making the buttons work
    [kam.py]
2025-06-14 updating bom and finding total cost
    [KrillKam Bom - Sheet1.csv]
2025-06-15 creating the windows for review & power
2025-06-17 making images scaled to fit screen
    I also added in code to allow the user to shuffle through photos with the buttons
2025-06-19 Power down image and journal update
2025-06-27 V3 of Case done
    [V3_Arm.stl, V3_ArmLock.stl, V3_Base.stl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]
